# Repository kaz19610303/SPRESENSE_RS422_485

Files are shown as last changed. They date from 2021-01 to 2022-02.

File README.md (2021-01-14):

Sonyのマイコンボード Spresense用のRS-422/485拡張ボードです。

RS-422/485通信はその長距離通信が可能な故に今でも工場とかでは幅広く使われています。  
RS-422、RS-485 共に***差動信号による伝送***で***10Mbps***のスピードで､最大***1.2km***までデータの伝送が可能です。  
RS-422とRS-485の違いは1ライン当たりのドライバ、レシーバーの数と全2重、Point to Pointと半2重、マルチドロップの違いです。  

RS-422/485に関する詳しい説明は省かせていただきますのでご自身で検索して下さい。  

このボードに使用しているRS-422/485のチップは***Analog Devices社のADM2582EBRWZ***です。  
このチップはロジック部分と通信部分がアイソレーションされていて、  
最高通信レート: 16 Mbps、1ラインに256ノードの接続可能となっています。  

詳しくは以下のデータシートをご覧下さい。  
[ADM2582EBRWZ データシート](https://www.mouser.jp/datasheet/2/609/adm2582e_2587e-1503113.pdf)  

ジャンパー設定  
SJ1　受信イネーブル制御ピン選択　1: EMMC_DATA3　3:I2S_DIN  
SJ2　送信イネーブル制御ピン選択　1: EMMC_DATA2　3:I2S_DOUT  
SJ3　ショートでRXラインの終端抵抗有効  
SJ4　ショート:RS-485 オープン:RS-422  
SJ5　ショート:RS-485 オープン:RS-422  
(SJ4とSJ5は両方オープンまたは両方ショートに設定してください)  
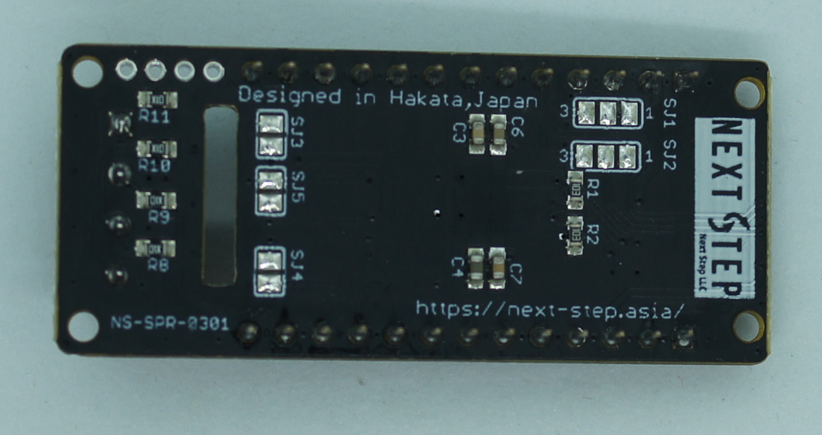
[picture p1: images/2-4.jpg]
基板上のジャンパー


CN3はアイソレーション電源出力です。  
1、2ピン 3.3v  
3、4ピン GND  
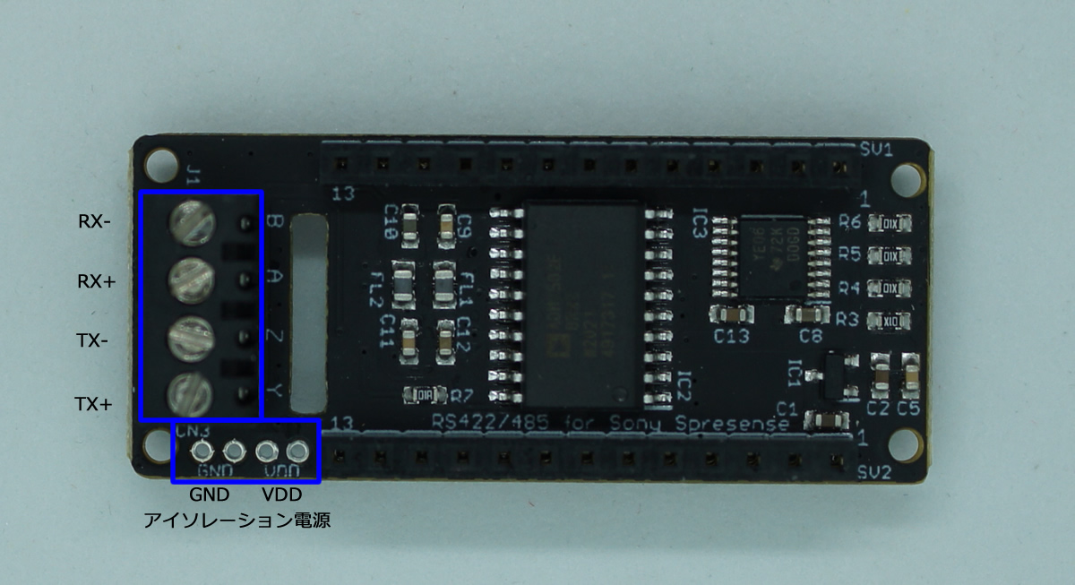
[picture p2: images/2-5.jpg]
外部接続端子


[この基板の販売ページ](https://nextstep.official.ec/items/38434310)

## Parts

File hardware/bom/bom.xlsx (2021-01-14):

Parts | Qty | Value | Device | Description | MANUFACTURER_NAME | MANUFACTURER_PART_NUMBER
C1, C2 | 2 | 1uF 6.3V 10 % | C-EUC0603K | CAPACITOR, European symbol | KEMET | C0603C105K8RAC
C3, C5, C7, C9, C11 | 5 | 100nF 6.3V 10 % | C-EUC0603K | CAPACITOR, European symbol | KEMET | C0603C104K8RACTM
C4, C10 | 2 | 10uF 6.3V 10% | C-EUC0603K | CAPACITOR, European symbol | Taiyo Yuden | JMK107ABJ106KA-T
C6, C12 | 2 | 10nF 6.3V 10 % | C-EUC0603K | CAPACITOR, European symbol | Wurth Elektronik | 885012206014
C8, C13 | 2 | 4.7uf 6.3V 10% | C-EUC0603K | CAPACITOR, European symbol | Samsung Electro-Mechanics | CL10A475KQ8NNNC
FL1, FL2 | 2 | BLM21PG121SN1D | BLM21PG121SN1D | BLM21_N1D Series EMI Suppression Filter 120+/-25% at 100MHz 3A @85 | Murata Electronics | BLM21PG121SN1D
IC1 | 1 | MCP1700T-3302E_TT | MCP1700T-3302E_TT | LDO voltage regulator 250mA Isupply 1uA | Microchip | MCP1700T-3302E/TT
IC2 | 1 | ADM2582EBRWZ | ADM2582EBRWZ | ADM2582EBRWZ, Line Transceiver 16Mbit/s Differential, 3.3 V, 5 V, 20-Pin SOIC W | Analog Devices | ADM2582EBRWZ
IC3 | 1 | TXB0106PWR | TXB0106PWR | 6-Bit Bidirectional Voltage-Level Translator with Auto Direction Sensing and +/-15-kV ESD Protect | Texas Instruments | TXB0106PWR
R1, R2 | 2 | 10k 1/10W 10% | R-US_R0603 | RESISTOR, American symbol | Vishay / Dale | CRCW060310K0JNEBC
R3, R4, R5, R6, R8, R9, R10, R11 | 8 | 10 1/10W 10% | R-US_R0603 | RESISTOR, American symbol | Vishay / Dale | CRCW060310R0FKEAC
R7 | 1 | 100 1/10W 10% | R-US_R0603 | RESISTOR, American symbol | Yageo | RC0603JR-07100RL
J1 | 1 | 1776112-4 | 1776112-4 |  | TE Connectivity | 1776112-4
SV1, SV2 | 2 |  | FE13-1 | FEMALE HEADER | 日本コネクト工業 | HSCSW-S13G-H3.5-L5.6
SJ1, SJ2 | 2 |  | SJ2W | SMD solder JUMPER
SJ3, SJ4, SJ5 | 3 |  | SJ | SMD solder JUMPER
CN1 | 1 | 1X4 | 1X4

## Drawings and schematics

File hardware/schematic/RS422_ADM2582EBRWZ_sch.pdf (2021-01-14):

## Spresense コネクター

# 13 SV2

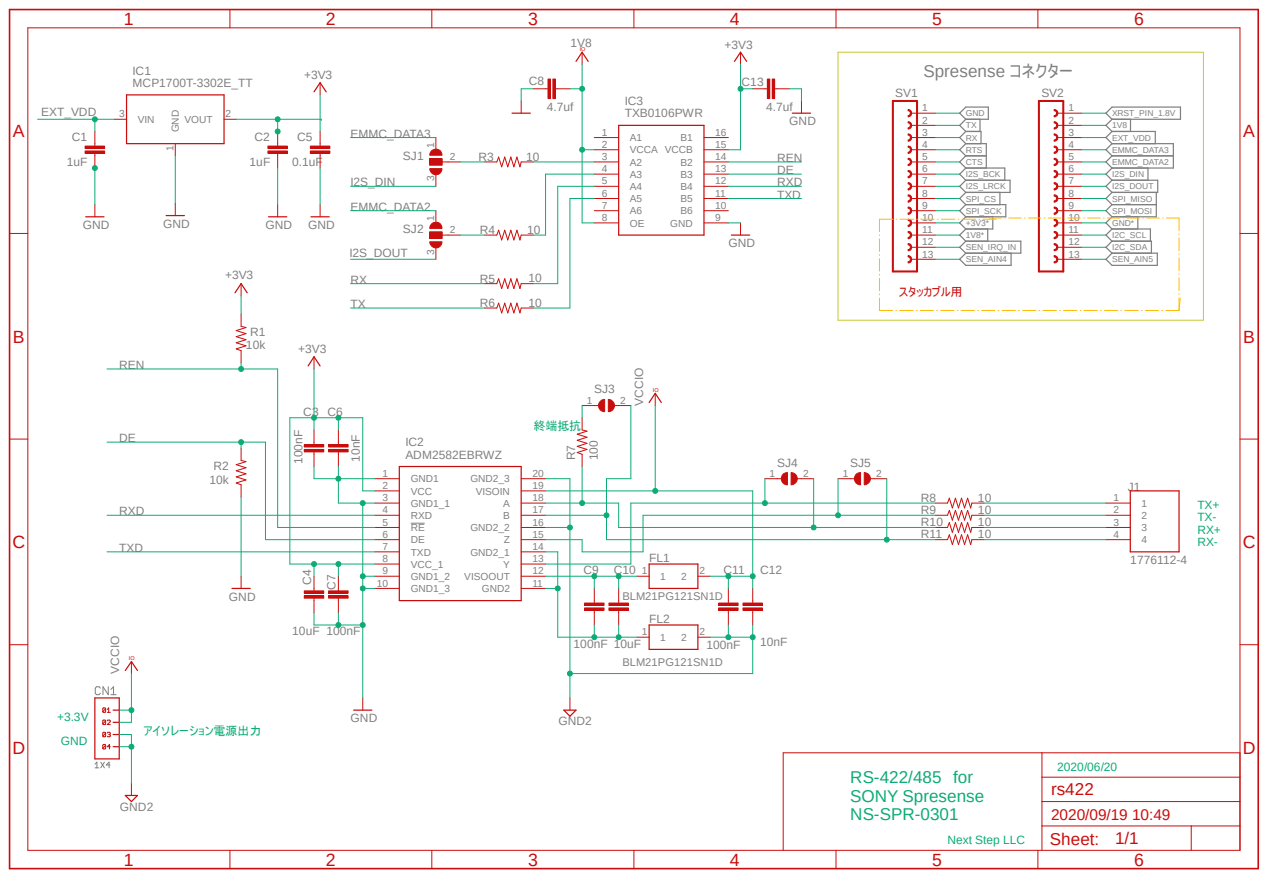
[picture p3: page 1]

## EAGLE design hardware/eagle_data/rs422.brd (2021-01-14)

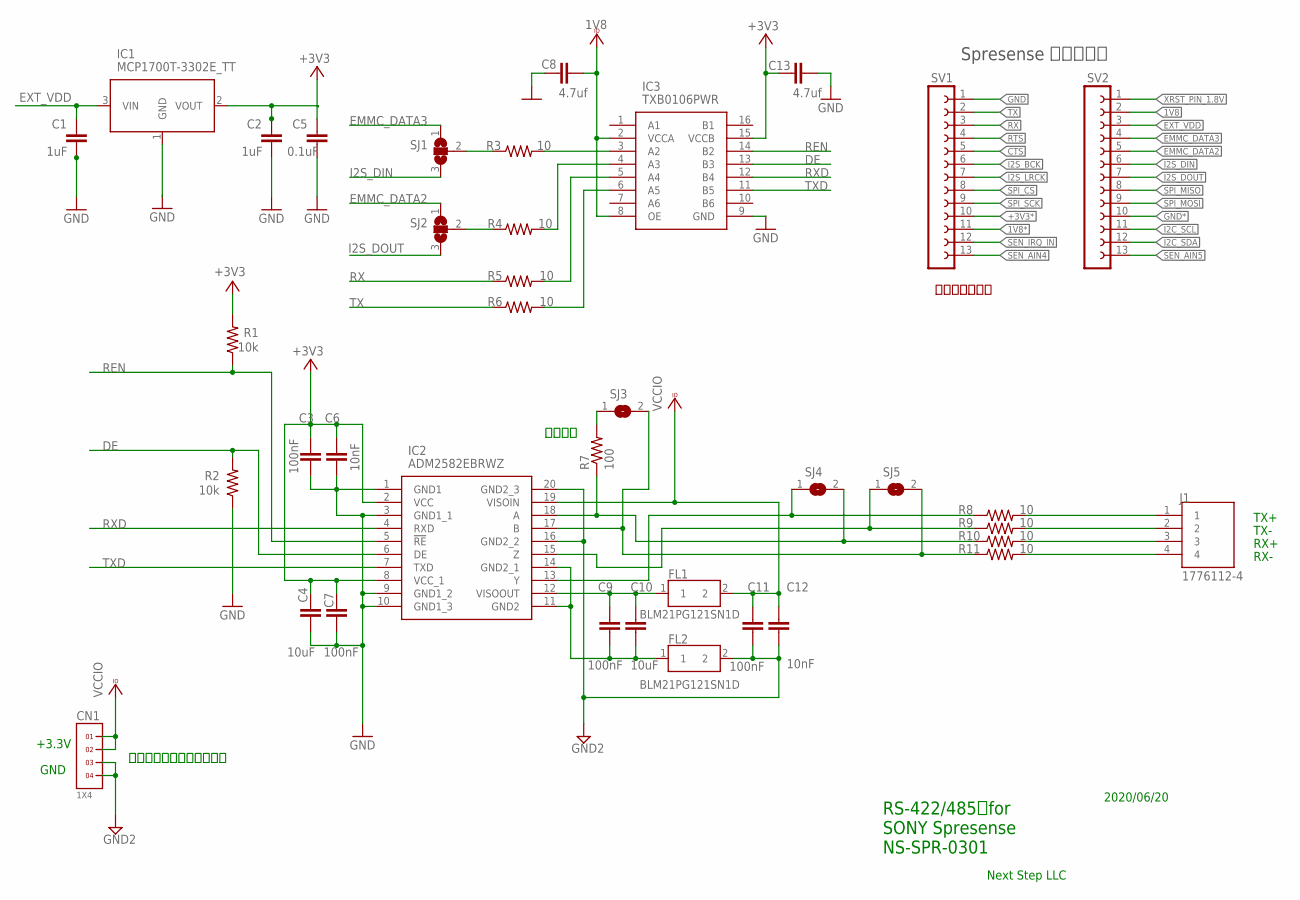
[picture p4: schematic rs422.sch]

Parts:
C1, C2: 1uF; C0603K
C3, C7, C9, C11: 100nF; C0603K
C4, C10: 10uF; C0603K
C5: 0.1uF; C0603K
C6, C12: 10nF; C0603K
C8, C13: 4.7uf; C0603K
CN1: 1X4
FL1, FL2: BLM21PG121SN1D; BEADC2012X105N
IC1: MCP1700T-3302E_TT; SOT95P237X112-3N
IC2: ADM2582EBRWZ; SOIC127P1032X265-20N
IC3: TXB0106PWR; SOP65P640X120-16N
J1: 1776112-4; TE_1776112-4
R1, R2: 10k; R0603
R3, R4, R5, R6, R8, R9, R10, R11: 10; R0603
R7: 100; R0603
SJ1, SJ2: SJ2W; SJ_2
SJ3, SJ4, SJ5: SJ
SV1, SV2: FE13-1; FE13

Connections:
1V8: C8.2, IC3.2 (VCCA), IC3.8 (OE), SV2.2
1V8*: SV1.11
+3V3: C2.1, C3.1, C4.1, C5.1, C6.1, C7.1, C13.1, IC1.2 (VOUT), IC2.2 (VCC), IC2.8 (VCC_1), IC3.15 (VCCB), R1.2
+3V3*: SV1.10
CTS: SV1.5
DE: IC2.6 (DE), IC3.13 (B3), R2.2
EMMC_DATA2: SJ2.1, SV2.5
EMMC_DATA3: SJ1.1, SV2.4
EXT_VDD: C1.1, IC1.3 (VIN), SV2.3
GND: C1.2, C2.2, C3.2, C4.2, C5.2, C6.2, C7.2, C8.1, C13.2, IC1.1 (GND), IC2.1 (GND1), IC2.3 (GND1_1), IC2.9 (GND1_2), IC2.10 (GND1_3), IC3.9 (GND), R2.1, SV1.1
GND2: C11.2, C12.2, CN1.3, CN1.4, FL2.2, IC2.16 (GND2_2), IC2.20 (GND2_3)
GND*: SV2.10
I2C_SCL: SV2.11
I2C_SDA: SV2.12
I2S_BCK: SV1.6
I2S_DIN: SJ1.3, SV2.6
I2S_DOUT: SJ2.3, SV2.7
I2S_LRCK: SV1.7
unnamed: IC2.13 (Y), R8.1, SJ4.1
unnamed: IC2.15 (Z), R9.1, SJ5.1
unnamed: IC2.18 (A), R7.1, R10.1, SJ4.2
unnamed: IC2.17 (B), R11.1, SJ3.2, SJ5.2
unnamed: C9.1, C10.1, FL1.1, IC2.12 (VISOOUT)
unnamed: R3.1, SJ1.2
unnamed: R7.2, SJ3.1
unnamed: IC3.3 (A2), R3.2
unnamed: IC3.4 (A3), R4.2
unnamed: IC3.5 (A4), R5.2
unnamed: C9.2, C10.2, FL2.1, IC2.11 (GND2), IC2.14 (GND2_1)
unnamed: IC3.6 (A5), R6.2
unnamed: R4.1, SJ2.2
unnamed: J1.1, R8.2
unnamed: J1.2, R9.2
unnamed: J1.3, R10.2
unnamed: J1.4, R11.2
REN: IC2.5 (!RE), IC3.14 (B2), R1.1
RTS: SV1.4
RX: R5.1, SV1.3
RXD: IC2.4 (RXD), IC3.12 (B4)
SEN_AIN4: SV1.13
SEN_AIN5: SV2.13
SEN_IRQ_IN: SV1.12
SPI_CS: SV1.8
SPI_MISO: SV2.8
SPI_MOSI: SV2.9
SPI_SCK: SV1.9
TX: R6.1, SV1.2
TXD: IC2.7 (TXD), IC3.11 (B5)
VCCIO: C11.1, C12.1, CN1.1, CN1.2, FL1.2, IC2.19 (VISOIN)
XRST_PIN_1.8V: SV2.1

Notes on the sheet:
TX+
TX-
RX+
RX-
Spresense コネクター
スタッカブル用
RS-422/485 for SONY Spresense NS-SPR-0301
+3.3V
GND
アイソレーション電源出力
終端抵抗
2020/06/20
Next Step LLC

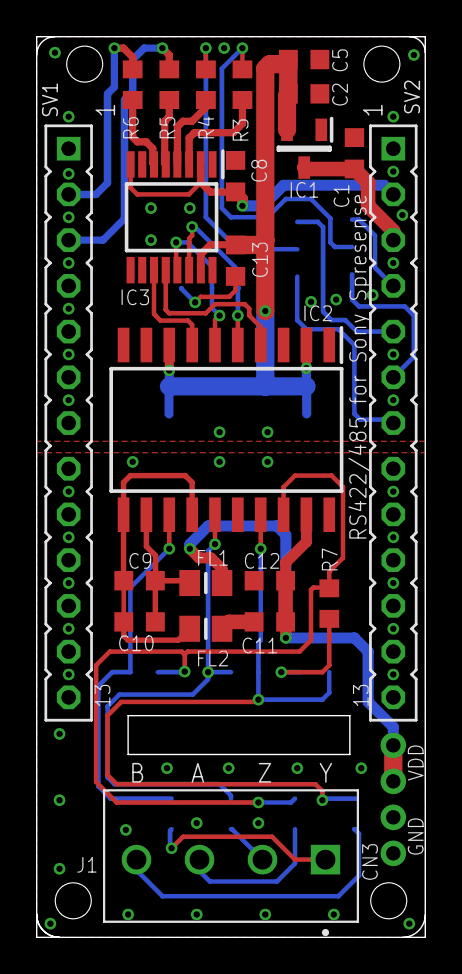
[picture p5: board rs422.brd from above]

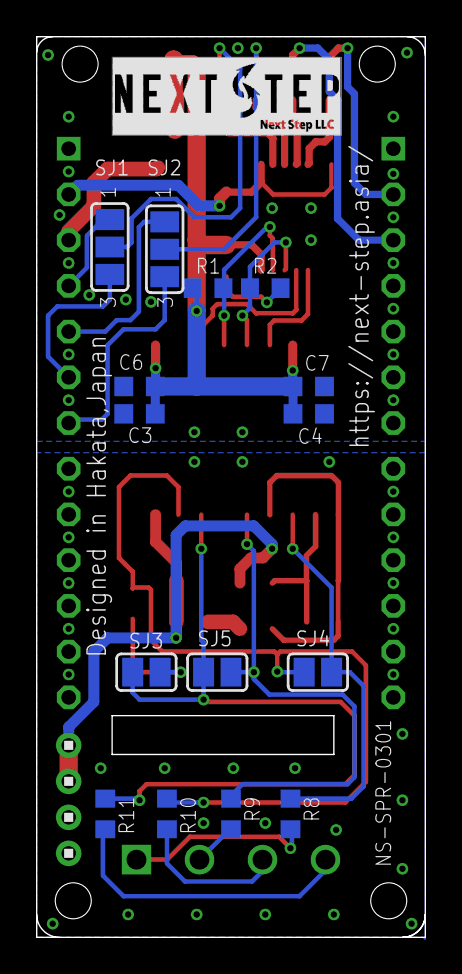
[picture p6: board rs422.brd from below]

Board: 2 copper layers, 21.6 x 50.0 mm, 38 parts (16 on the bottom side), 33 nets.

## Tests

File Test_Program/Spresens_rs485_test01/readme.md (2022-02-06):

**Spresens rs-485 Multi Drop test program**

3枚の基板を使ってRS-485のテストを行います。
実際は3枚の基板に対してのマスター・スレーブの制御が必要となりますが、今回は単純に3枚の基板から別々のデータを送信しています。
よって送信のタイミングが重なった場合は正常に動きません。

**事前準備**  
SJ1　受信イネーブル制御ピン選択　1: EMMC_DATA3  
SJ2　送信イネーブル制御ピン選択　1: EMMC_DATA2  
SJ3　ショート RXラインの終端抵抗有効 (両端の2枚)  
SJ4　ショート:RS-485  
SJ5　ショート:RS-485  

3枚の基板の Y Z または A B どうしを接続
  
**プログラム**  
spresense_rs485_unit1.ino  
　送信データ "1234567890"  

spresense_rs485_unit2.ino  
　送信データ "9876543210"

spresense_rs485_unit3.ino  
　送信データ "ABCDEFGHIJKLMNOPQRSTUVWXYZ"

**実行結果**

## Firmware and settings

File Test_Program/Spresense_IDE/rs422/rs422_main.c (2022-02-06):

#include <sdk/config.h>
#include <stdio.h>
#include <stdlib.h>
#include <string.h>
#include <fcntl.h>
#include <termios.h>
#include <unistd.h>
#include <poll.h>

#include <arch/board/board.h>
#include <arch/chip/pin.h>

#define RX_ENABLE PIN_EMMC_DATA3
#define TX_ENABLE PIN_EMMC_DATA2


int rs422_main(int argc, char *argv[])
{
    int fd;
    struct termios tio;                                     // シリアル通信設定
    int baudRate = B115200;
    int i;
    int len;
    int ret;
    int size;

    board_gpio_config(RX_ENABLE, 0, false, false, 0);       // 受信イネーブル Active LOW
    board_gpio_config(TX_ENABLE, 0, false, false, 0);       // 送信イネーブル Active HIGH
 
    board_gpio_write(RX_ENABLE, 0);                         // 受信は常時イネーブル
    board_gpio_write(TX_ENABLE, 0);                         // 送信は通常ディスイネーブル

    fd = open("/dev/ttyS2", O_RDWR);
    if (fd < 0)
    {
         printf("%s open error.\n", "/dev/ttyS2");
         return -1;
    }

    tio.c_cflag += CREAD;                                   // 受信有効
    tio.c_cflag += CLOCAL;                                  // ローカルライン（モデム制御なし）
    tio.c_cflag += CS8;                                     // データビット:8bit
    tio.c_cflag += 0;                                       // ストップビット:1bit
    tio.c_cflag += 0;                                       // パリティ:None

    cfsetispeed( &tio, baudRate );
    cfsetospeed( &tio, baudRate );
    cfmakeraw(&tio);                                        // RAWモード
    tcsetattr( fd, TCSANOW, &tio );                         // デバイスに設定を行う
    ioctl(fd, TCSETS, &tio);                                // ポートの設定を有効にする

    for(int i=0; i<50 ; i++)
    {
        board_gpio_write(TX_ENABLE, 1);                     // 送信イネーブル
        write_serial(fd);
        board_gpio_write(TX_ENABLE, 0);                     // 送信ディスイネーブル
        read_serial(fd);
        usleep(1000*1000);                                  // 1秒遅延
    }
}

void write_serial(int fd)
{
    char buffer[255];
    int send_data_lengs ;
    int delay_times = 1;

    memset(buffer,0,sizeof(buffer));
    sprintf(buffer,"%s","1234567890abcdefghijklmnopqrstuvwxyz\r\n");
    send_data_lengs = strlen(buffer);
    write(fd,buffer,send_data_lengs);
    printf("[write_serial]wrote = %s", buffer);
    usleep( 1 );                                            // 送信終了までの遅延 要調整
}

void read_serial(int fd)
{
    char buffer[255];
    int len;

    len = read(fd,&buffer,255);
    if(len > 0)
    {
        printf("[read_serial]buffer = %s\n", buffer);
    }
    else
    {
        printf("[read_serial]null\n");
    }
}

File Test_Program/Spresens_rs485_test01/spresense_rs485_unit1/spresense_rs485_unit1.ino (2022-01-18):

/*
  Spresense RS-422/485 ボード(NS-SPR-0301)　テストプログラム
  rS-422/485 test
  Set Jummper
  SJ1　1-2ショート　　
  SJ2　1-2ショート　　
  SJ3　ショート
  SJ4　ショート
  SJ5　ショート

  Next Step LLC
  https://next-step.asia/
  https://github.com/kaz19610303/SPRESENSE_RS422_485
*/

#define Receive_Enable 21                     // 受信許可ピン Active LOW
#define Transmit_Enable 20                    // 送信許可ピン Active High


void setup() {
  // initialize both serial ports:
  Serial.begin(115200);                         // Monitor terminal
  Serial2.begin(115200);                        // RS-422/485 terminal
  pinMode(21,OUTPUT);
  pinMode(20,OUTPUT);
  digitalWrite(Receive_Enable, LOW);          // Receive Enable
}

void loop() {
  Serial.println("Send unit_1 : 1234567890");
  digitalWrite(Transmit_Enable, HIGH);        // Transmit Enable
  Serial2.println("1234567890");              // Send RS-422/485 
  Serial.flush();
  digitalWrite(Transmit_Enable, LOW);         // Transmit Enable
  while (Serial2.available()) {               // Recive RS-422/485
    Serial.write(Serial2.read());             // Send Monitor terminal 
  }
  delay(1000);
}
